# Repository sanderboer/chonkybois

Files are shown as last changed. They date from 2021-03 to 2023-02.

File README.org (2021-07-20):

* Lil Chonky Bois.

MX hotswap, wireless version.
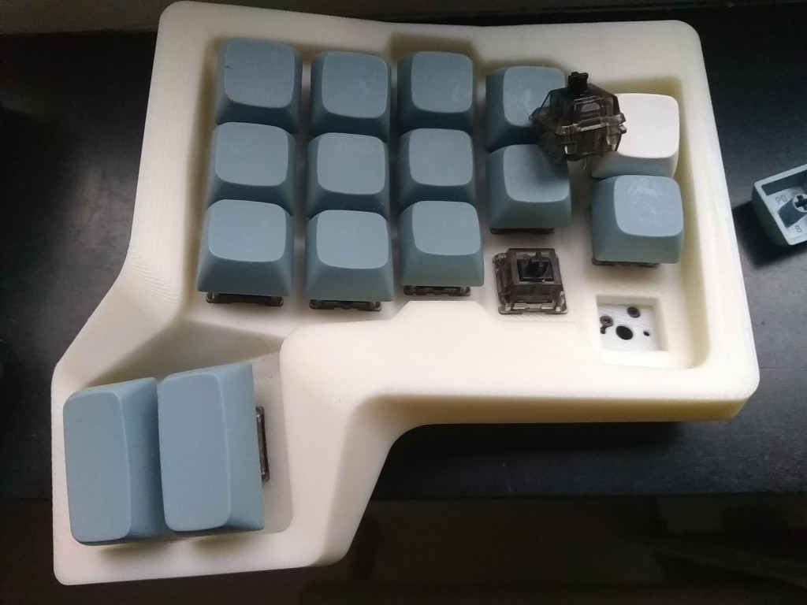
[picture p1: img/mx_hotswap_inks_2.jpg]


This is the case design for the Lil Chonky Bois, the successor of the original Chonky Boi, which has been moved to the archive.
The Chonky Bois come in different flavors, i.e. wired and wireless. The wireless version accomodates the [[https://store.jpconstantineau.com/#/group/bluemicro][bluemicro840 v1.x]] and the [[https://store.jpconstantineau.com/#/group/bluemicro][bluemacro840 v1.x]]. Rumor has it that the Nice!Nanos are going to be in stock again in the nearnear future, when I can get a hold of a couple, I will update this repo with a holder for it, providing the original promicro holder will not suffice.
Furthermore, MX hotswap and ALPS mountplate versions are provided.

* Hot Swap
Having started with handwired alps keyboards, repurposing AEKII switches, I turned my nose up to hotswappable keyboards. This was wrong, like very wrong. What I did not know at the time was how rich and diverse the MX switch landscape had become. At the time I only had silent white alps and if I looked far and wide on the internet, maybe, just maybe I could find a batch of affordable blue or orange alps. Three types of switches was managable.

When I made an MX version I quickly fell into a rabbit hole of blues (yuck), browns (oof), yellows (hello), glorious pandas (wat) and black inks (fuyooo) and I have barely scratched the surface. No, like lubing and filming your switches, I now consider hotswap to be *mandatory* for any keyboard enthousiast. I manage to solder a set in roughly two hours and my back hates it, if I see a nice switch set on ali (I see you tecsee purples) I do not want to think about breathing soldering fumes for another evening. No, I want to think about the taste of krytox 205g0 on my fingers instead ! /s

* Extras

** Wrist rests
For conveniece, several wrist rests are provided in a separate blend file, the gel version has also been exported as an stl. Please note that I am using some weird rubber feet I found in a craft store, sold by the pound and you will need to accomodate accordingly.

** Switch fit tester / Super Awesome Fidget Unit.
Essentially I lifted three homerow keys out of the right side and modeled it into a tester to test switch fit and to test the switch feel.
Put a lubed and unlubed switch in here and amaze your friends !
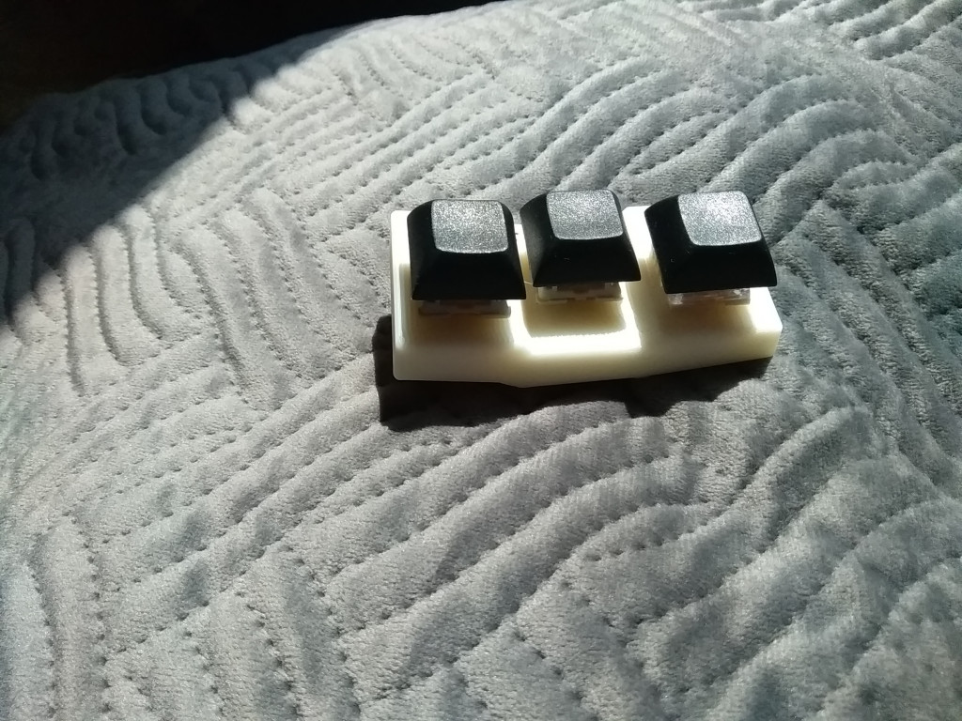
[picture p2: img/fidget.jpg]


* BOM

** General
| type                                 | amount | remarks                                                                               | link      |
|                                      |        |                                                                                       |           |
|--------------------------------------+--------+---------------------------------------------------------------------------------------+-----------|
| knurled inserts                      |     12 | M3 x D5 x  L4.0                                                                       | [[https://nl.aliexpress.com/item/4000232858343.html][ali]]       |
| m3 screws                            | 6 or 8 | flathead or roundhead                                                                 | [[https://nl.aliexpress.com/item/4000742472778.html?spm=a2g0o.store_pc_groupList.8148356.1.4b54694dlYVj6k][ali]]       |
| Kailh hotswap sockets                |     34 |                                                                                       | [[https://nl.aliexpress.com/item/4001051840976.html?spm=a2g0s.9042311.0.0.27424c4duT8R5v][ali]] [[https://ymdk.nl.aliexpress.com/store/429151][ymdk]]  |
| switches                             |     34 | glorious pandas (tactile), gateron inks (linear) or kailh box blues (clicky) or...    | [[https://nl.aliexpress.com/item/1005001678253507.html?spm=a2g0s.9042311.0.0.27424c4dcuYsDy][ali]] [[https://ymdk.nl.aliexpress.com/store/429151][ymdk]]  |
| switch lube and station              |    n/a | Optional, but if you are not lubing your switches, why are you here ?                 | [[https://nl.aliexpress.com/item/4001287632004.html?spm=a2g0s.9042311.0.0.27424c4dP1bmnZ][ali]] [[https://ymdk.nl.aliexpress.com/store/429151][ymdk]]  |
| 1n4148 diodes                        |     34 |                                                                                       | [[https://nl.aliexpress.com/item/1934432186.html?spm=a2g0s.9042311.0.0.27424c4dCcuaFD][ali]]       |
| grippy rubber                        |    n/a | To keep the kb from sliding, harder to find than I'd like to admit                    | [[https://nl.aliexpress.com/item/4000013831045.html?spm=a2g0s.9042311.0.0.27424c4d6xGt3Y][ali]]       |
| color coated copper wire             |        | Optional, but the color coding and the thin wires really suit this project            | [[https://www.aliexpress.com/item/1005001321847977.html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,searchweb201602_,searchweb201603_][ali]]       |
| keycaps dsa/xda                      |     34 | 30x1u and 4x1.5u                                                                      | [[https://nl.aliexpress.com/item/1005001376888502.html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,scm-url:1007.30114.213637.0,pvid:67330b30-a52a-417b-af98-0368b264de63,tpp_buckets:668%230%23131923%2375_668%23888%233325%2311_20114%230%23213637%235_20114%233258%2310449%2333_668%232846%238114%231999_668%235811%2327185%2368_668%236421%2330822%23182_668%232717%237567%23922__668%233374%2315176%23590_19670%230%23233084%230_19670%233636%2316450%23358_19670%234867%2324465%23166_19670%235271%2324224%23319_19670%233633%2316436%23436_19670%232760%237734%23528_19670%233043%239190%239_19670%235119%2323475%23944&&pdp_ext_f=%257B%2522scene%2522%253A%252220114%2522%257D][ali]]  [[https://ymdk.nl.aliexpress.com/store/429151][ymdk]] |
| gel superglue                        |      1 | The hotswap sockets are glued in place, gel is better with filling printed gaps      | [[https://www.bol.com/nl/nl/p/pattex-superglue-ultra-mini-gel-trio-3-tubes-1-g/9200000124384556/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][bol]]       |
|--------------------------------------+--------+---------------------------------------------------------------------------------------+-----------|
| WIRELESS                             |        |                                                                                       |           |
| bluemicro840 v1.x/bluemacro 840 v1.x |      2 | Do not mix micro and macro                                                           | [[https://store.jpconstantineau.com/#/group/bluemicro][store]]     |
| micro reset switch                   |      2 | Hardware reset switch; boards need double click to be put into dfu mode              | [[https://nl.aliexpress.com/item/32919212895.html?spm=a2g0s.9042311.0.0.27424c4dsfyf3P][ali]]       |
| jst connector                        |      1 | one 4-pin male and female;disconnecting the botplate is a quality of life option.    | [[https://nl.aliexpress.com/item/32963843207.html?spm=a2g0s.9042311.0.0.27424c4dZ8ET6k][ali]]       |
| On/Off switch                        |      2 |                                                                                       | [[https://nl.aliexpress.com/item/32952489874.html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][ali]]       |
| LiPo battery                         |      2 | Shipping to your country could be an issue, check local drone tech suppliers.         | [[https://nl.aliexpress.com/item/32977525312.html?spm=a2g0s.9042311.0.0.27424c4dynClON][ali]]       |
|--------------------------------------+--------+---------------------------------------------------------------------------------------+-----------|
| WIRED                                |        |                                                                                       |           |
| Pro Micro MCU                        |      2 | Elite-C (usb-c) or teensy 2.0 (usb-mini) are viable alternatives                      | [[https://nl.aliexpress.com/item/32768308647.html?spm=a2g0s.9042311.0.0.27424c4dS8z6Py][ali]]       |
| TRSS connector                       |      2 | Needs to be stereo                                                                   | [[https://nl.aliexpress.com/item/4000640677390.html?spm=a2g0s.9042311.0.0.27424c4dX6v9oC][ali]]       |
| TRSS cable                           |      1 | Or any old male-male stereo 2.5 mm jack audio aux cable.                              | [[https://nl.aliexpress.com/item/32459681560.html?spm=a2g0s.9042311.0.0.27424c4dynClON][ali]]       |
|--------------------------------------+--------+---------------------------------------------------------------------------------------+-----------|
| ALPS                                 |        |                                                                                       |           |
| Alps no name clone                   |        | Still waiting on delivery,so untested as yet. Get an old apple AEKII on ebay instead. | [[https://nl.aliexpress.com/item/32654107324.html?spm=a2g0s.9042311.0.0.2b254c4drfqukj][ali]]       |
|--------------------------------------+--------+---------------------------------------------------------------------------------------+-----------|
| MISC / Quality of life               |        |                                                                                       |           |
| Gel wrist rest                       |      2 |                                                                                       | [[https://nl.aliexpress.com/item/32894937019.html?spm=a2g0s.9042311.0.0.27424c4d6VJaFU][ali]]       |
| Crimp tool                           |      1 | For your jst connectors, and the molex connectors in your maker future.              | [[https://nl.aliexpress.com/item/32910569929.html?spm=a2g0s.9042311.0.0.27424c4dZ8ET6k][ali]]       |
| Superglue accelerator / activator    |        | Check your local hardware store.                                                      |           |

* Firmware

** Wired
For the wired version, QMK is the way to go, I maintain a form of qmk with a keymap for the Lil Chonky Bois:

https://github.com/sanderboer/qmk_firmware

** Wireless

*** BluemicroBLE
Similarly I maintain my keymap for the wireless build in my own fork of BlueMicroBLE (lil_chonky_kb branch):

https://github.com/sanderboer/BlueMicro_BLE/tree/lil_chonky_kb

Please refer to the BlueMicroBLE docs for installing the build env, additional setup and build script for linux is in the root of my for of the repo.
Please let me express my extreme gratitude to [[https://github.com/jpconstantineau/][Pierre Constantineau]], the creator of the bluemicro840, for his extremely patient and helpful guidance on discord in setting up the boards and showing me just how deep the rabbit hole of bluetooth voodoo goes. 

*** ZMK
And as an alternative I also have my keymap implemented in my ZMK fork (lil_chonky  branch):

https://github.com/sanderboer/zmk/tree/lil_chonky

Please refer to the ZMK docs for setup the build env, build script for linux is in the app/boards/shields/lil_conky_bois/ dir
* Images

Bluemacro840 under construction
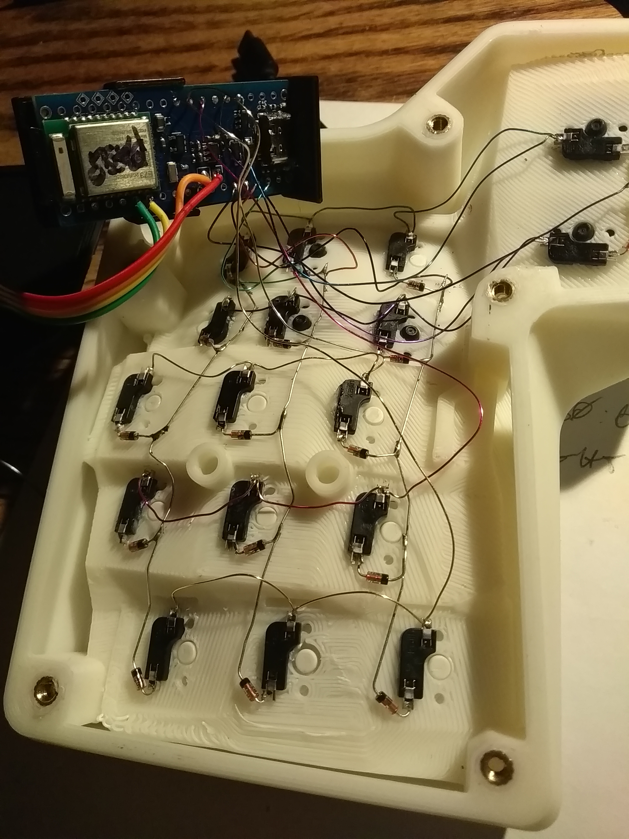
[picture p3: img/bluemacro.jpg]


Wired version in the background with wrist rests, wired version showing its guts. Note the removable botplate thanks to the jst connectors.
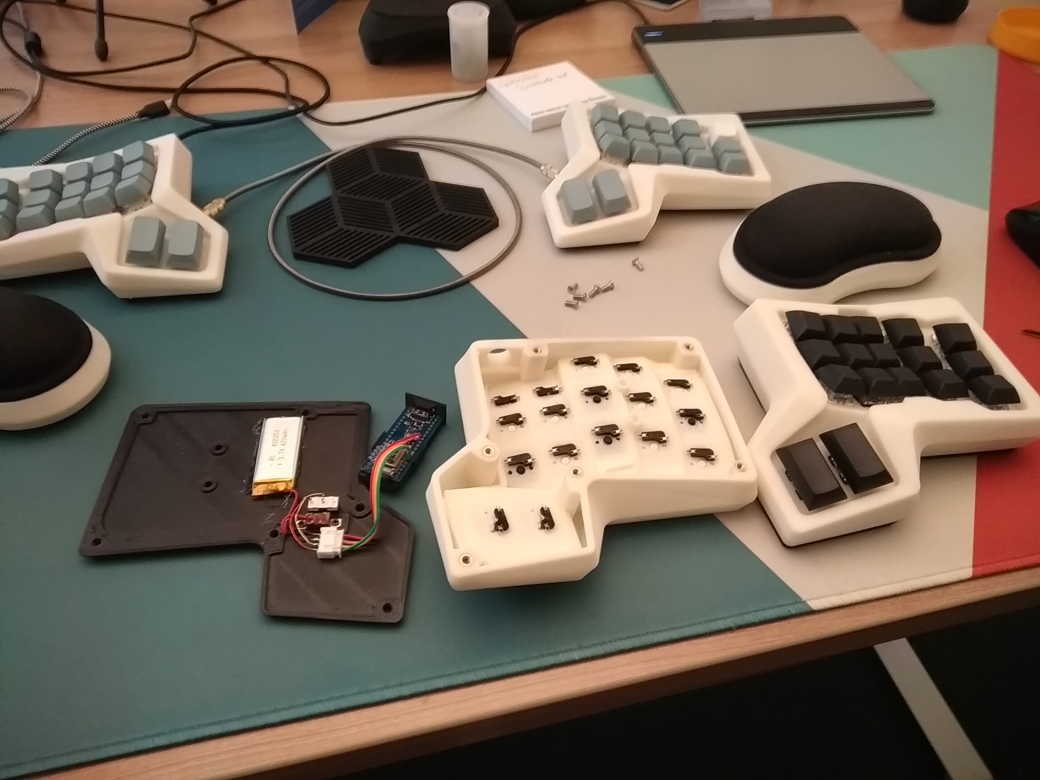
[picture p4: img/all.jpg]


The original Big Chonky Bois and Lil CHonky Bois that started it all.
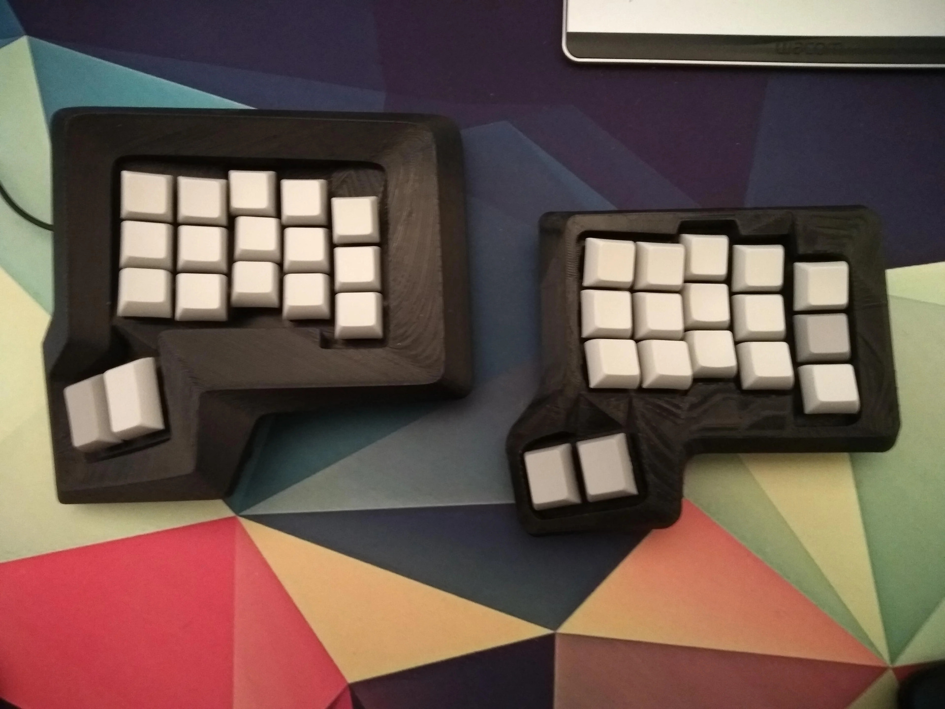
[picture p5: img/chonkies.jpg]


Lil Chonky in ALps and MX version. 


Wired version, XDA keycaps.





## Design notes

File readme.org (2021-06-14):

* Lil Chonky v 1.1

#+CAPTION: Lil Chonky in ALps and MX version. 


This is the next iteration of the original lil Chonkster, after using the previous incarnation for a couple of months I decided to ease the tenting and I found I needed a little less curvature of the keywell. After some testing I also adapted the thumbcluster a little. Pictured are the Alps and the MX version, the thumbcluster is designed for 1.75u keycaps and for MX keys these are harder to come by than imagined. In the BOM is a link to an ALI store that allows you to order any format, but 1.75u is calculated as having the price of 4x 1u.

* Punk Rock Hot Swap
Strictly speaking this is not part of the design, but it is part of my build. During the design iterations I changed cases a number of times and I got real sick of the resoldering. Not so much the work itself, but I felt there was a real degradation happening with each resolder.
I found an example of somebody using small rivets in stead of the mill-max connectors. The plan is to put a small rivet over one of the legs of a switch, use pliers to squash the rivet on the leg. Then comes the intersting bit, this squashed rivet will too easily come off, now you must remove the rivet from the leg and give it an extra squeeze. Too hard and it will not go over the leg again, too little, it will come loose too easily, repeat until a healthy friction fit is achieved.




* BOM



- 12 x knurled inserts M3 x D5 x  L4.0
https://nl.aliexpress.com/item/4000232858343.html
- rivets for punk rock hotswap
https://nl.aliexpress.com/item/32955662951.html
- 12 m3 x 6(or 8) screws. I had round head laying around, but flat heads are more practical: https://nl.aliexpress.com/item/4000742472778.html?spm=a2g0o.store_pc_groupList.8148356.1.4b54694dlYVj6k

- 34 switches.These Holy Pandas are amaze and kinda awesome: https://nl.aliexpress.com/item/1005001678253507.html?spm=a2g0s.9042311.0.0.27424c4dcuYsDy

- (optional) switch lube, station and opener https://nl.aliexpress.com/item/4001287632004.html?spm=a2g0s.9042311.0.0.27424c4dP1bmnZ

- 2 x TRSS connectors

- 34 x 1n4148 diodes. https://nl.aliexpress.com/item/1934432186.html?spm=a2g0s.9042311.0.0.27424c4dCcuaFD

- 30x dsa 1u keycaps, 4x  dsa 1.75u keycaps https://nl.aliexpress.com/item/32850729893.html

- 2x pro micro https://nl.aliexpress.com/item/32768308647.html?spm=a2g0s.9042311.0.0.27424c4dS8z6Py

- 1x sticky grippy rubber mat. https://nl.aliexpress.com/item/4000013831045.html?spm=a2g0s.9042311.0.0.27424c4d6xGt3Y

- (optional) color coated copper wire.
  untested link of a product that looks like the one I am using: https://www.aliexpress.com/item/1005001321847977.html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,searchweb201602_,searchweb201603_
  
* Images









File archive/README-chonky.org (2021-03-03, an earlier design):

* Chonky Bois

#+CAPTION: Big Chonky and the first lil Chonky.


 This is the home of the Chonky Bois ergo split keyboard models.
 Here you can find 3d models that once printed, fit alps or mx switches, a trss connector and a pro-micro and after some handwiring magic you can head over to my qmk fork for an example of a keymap/ 

** Lil Chonky
What started with the Big Chonky evolved into a more petite size.

#+CAPTION: Lil Chonky with the pinky rotation.


For this one I wrote a quick port of Matt Adereth's dactyl code to generate the shape of the keywells and the shape of the cavities for the switches. The intention is that one can model a basic shape around the generated keywell shapes.
I added a pinky rotation option as I found it to be very comfortable on the Absolem keyboard.

Generated model:


Finale model example:
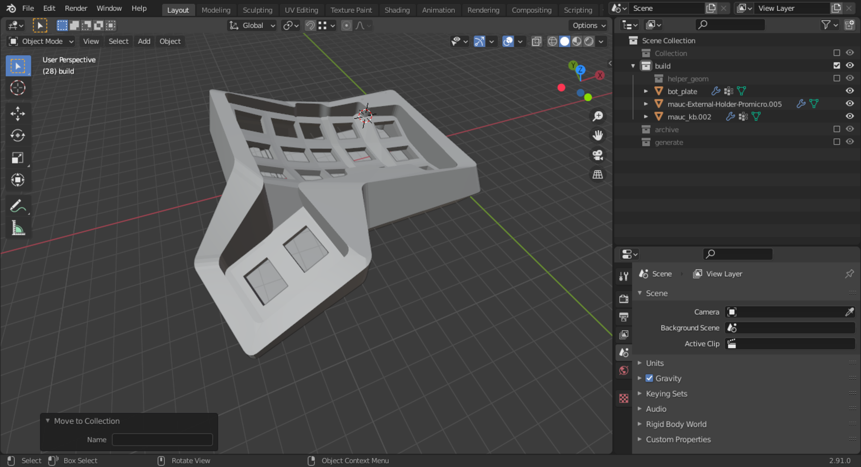
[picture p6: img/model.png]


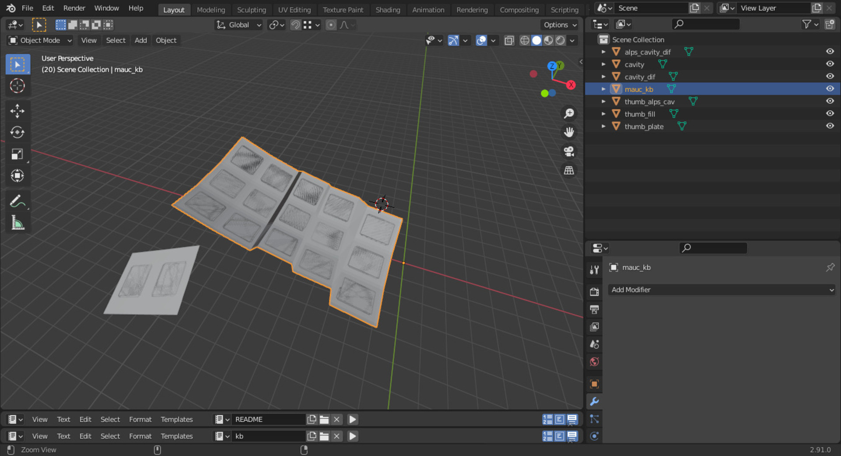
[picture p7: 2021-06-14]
img/generate.jpg

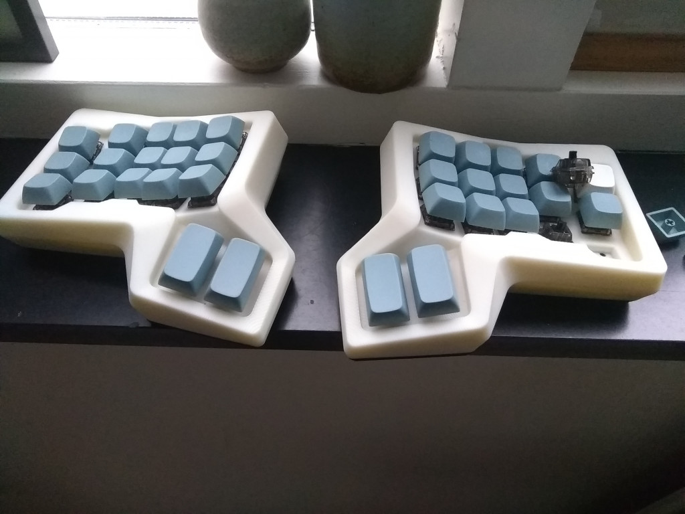
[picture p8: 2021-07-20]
img/bt.jpg

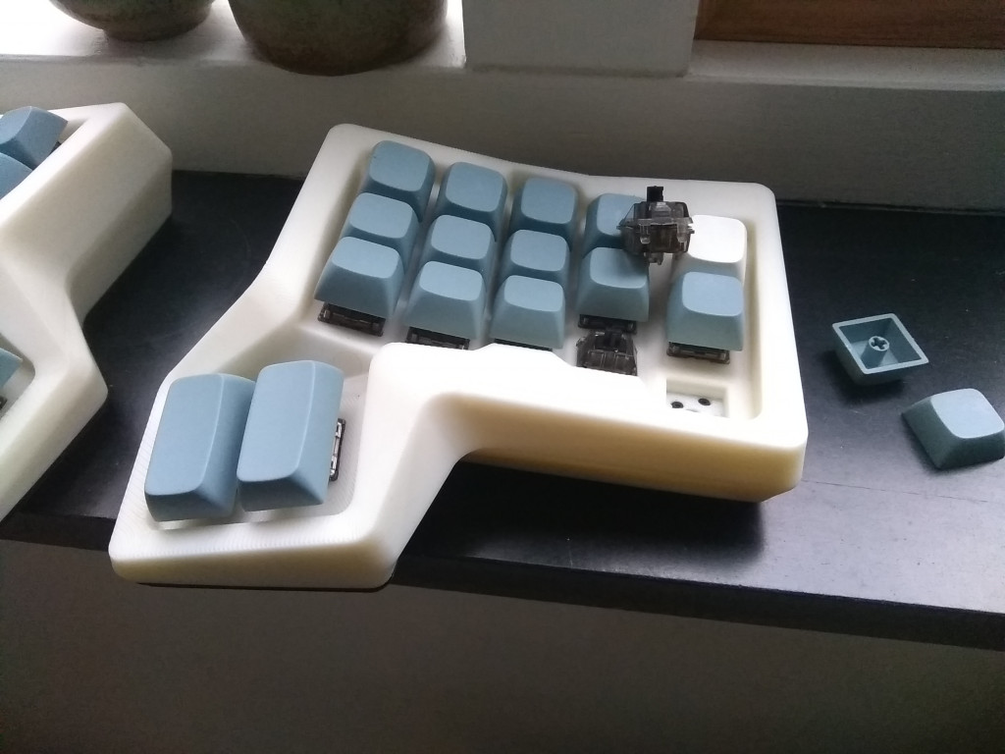
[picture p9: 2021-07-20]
img/mx-hotswap-inks.jpg

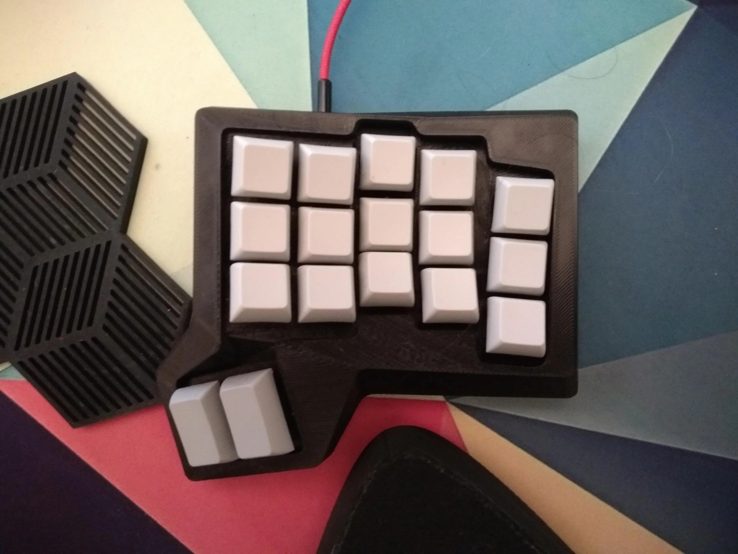
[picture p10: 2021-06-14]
img/lil_top.jpg

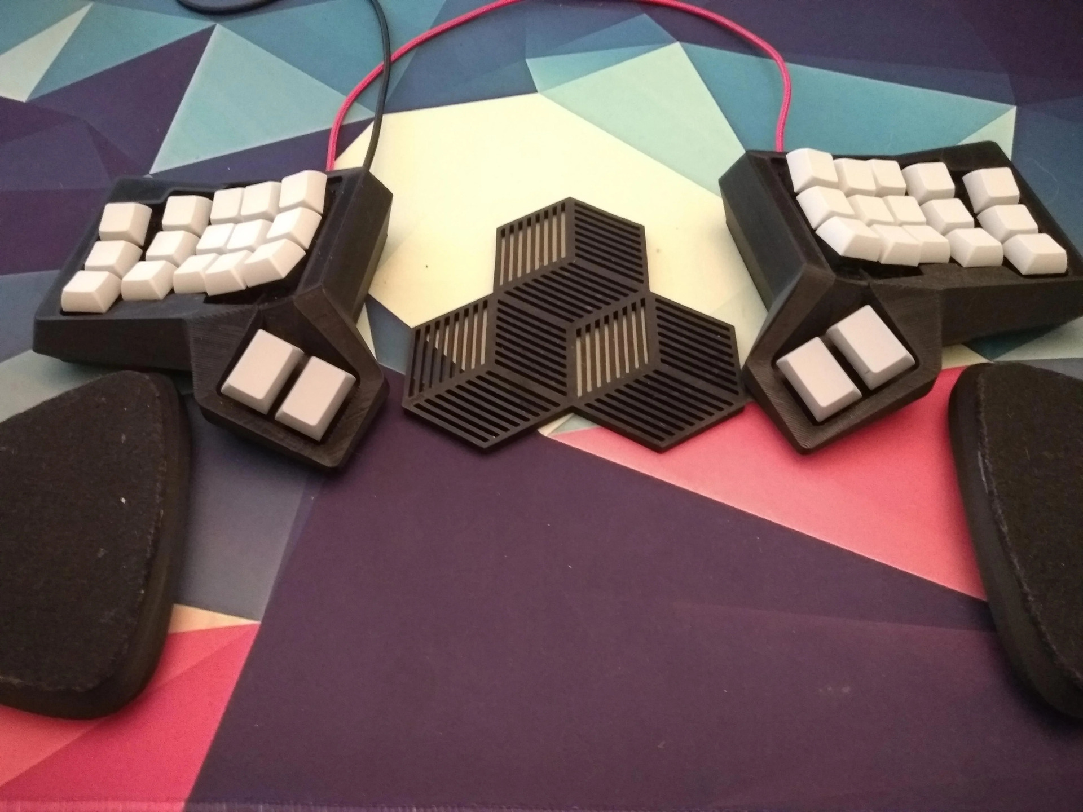
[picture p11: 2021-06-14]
img/lil.jpg

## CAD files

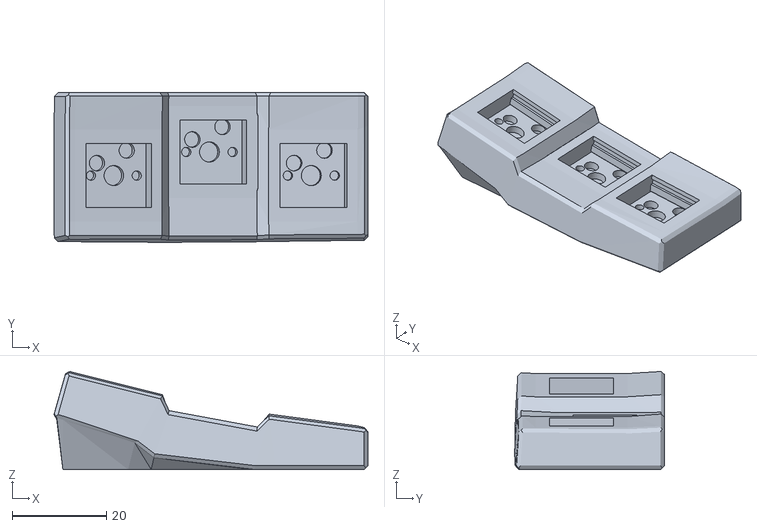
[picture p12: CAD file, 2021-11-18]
fidget_tester.stl
66.5 x 31.7 x 20.8

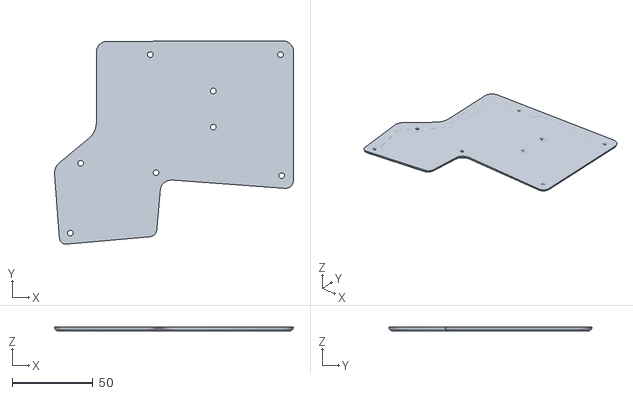
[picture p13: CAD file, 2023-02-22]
stl_wired/case_bot_right_wired_solid.stl
147.6 x 125.5 x 2.18

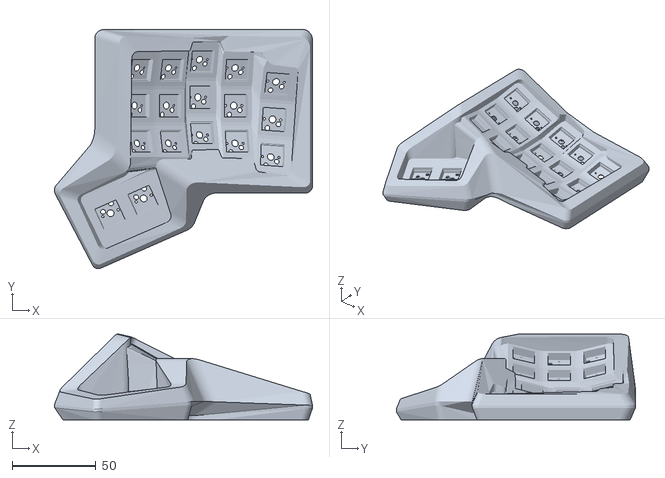
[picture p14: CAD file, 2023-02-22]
stl_wireless/generator_3x5-curvycase-right.stl
154.2 x 143.1 x 51.3

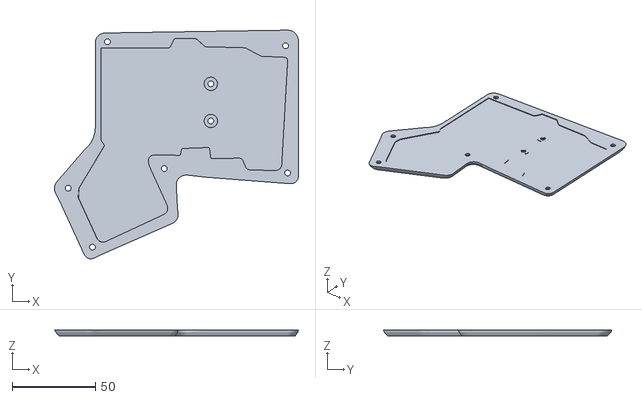
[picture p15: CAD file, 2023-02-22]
stl_wired/curvy-3x5-case-right-bot.stl
146.3 x 137.2 x 3.68

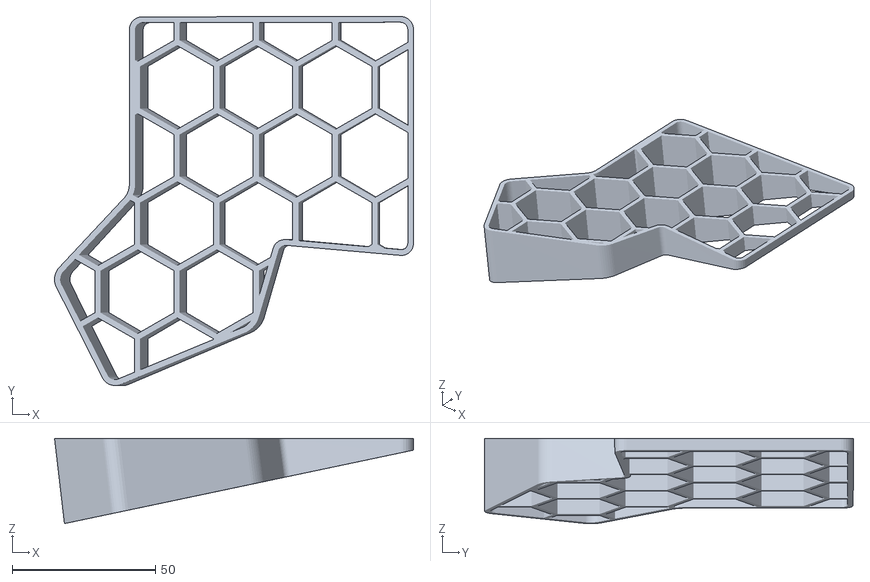
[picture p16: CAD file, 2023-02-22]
stl_wireless/generator_3x5-curvycase_009.stl
125.4 x 128.9 x 29.8

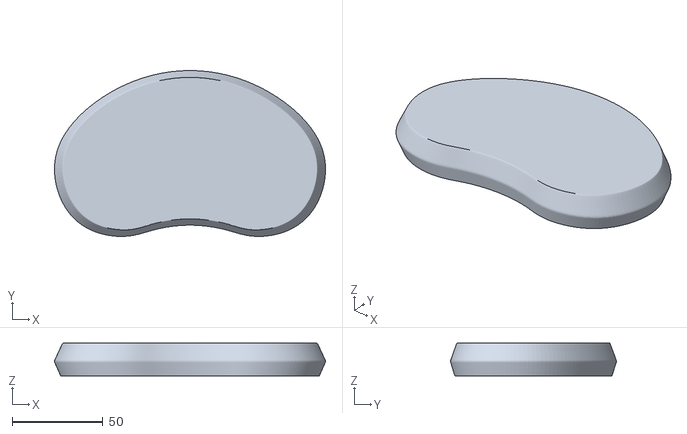
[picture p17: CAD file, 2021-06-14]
wrist-rest-gel_x2.stl
149.2 x 91.3 x 18.1

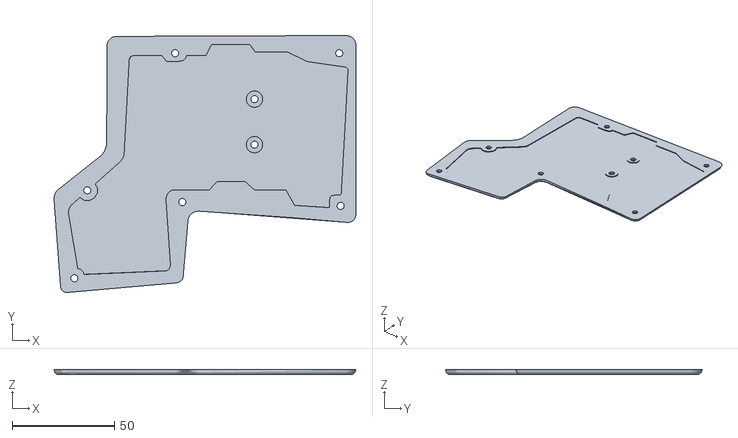
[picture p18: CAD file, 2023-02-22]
stl_wired/case_bot_right_wired_micro_solid.stl
147.9 x 125.9 x 2.43

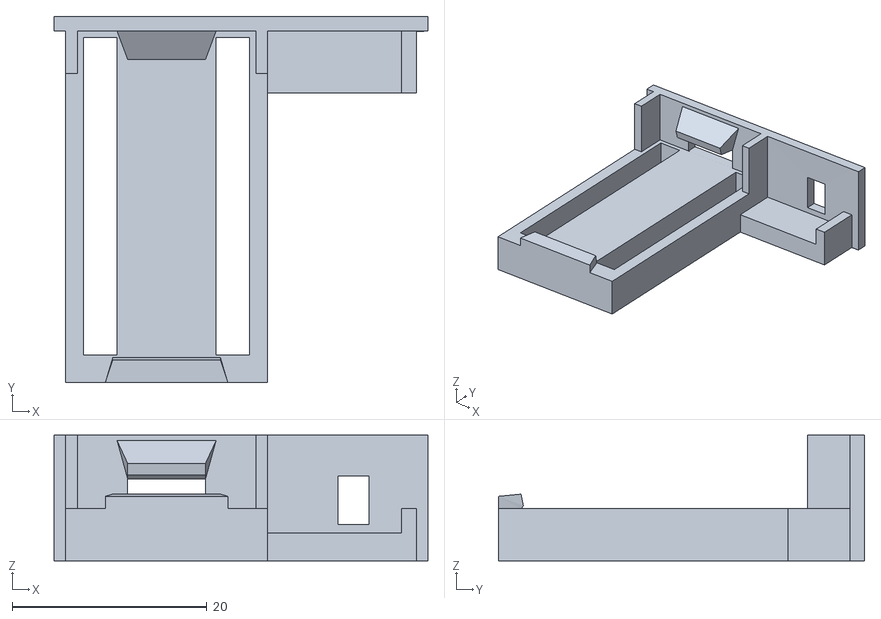
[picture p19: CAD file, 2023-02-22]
stl_wireless/generator_3x5-curvymauc-External-Holder-nicenano_x2.stl
38.4 x 37.7 x 12.9

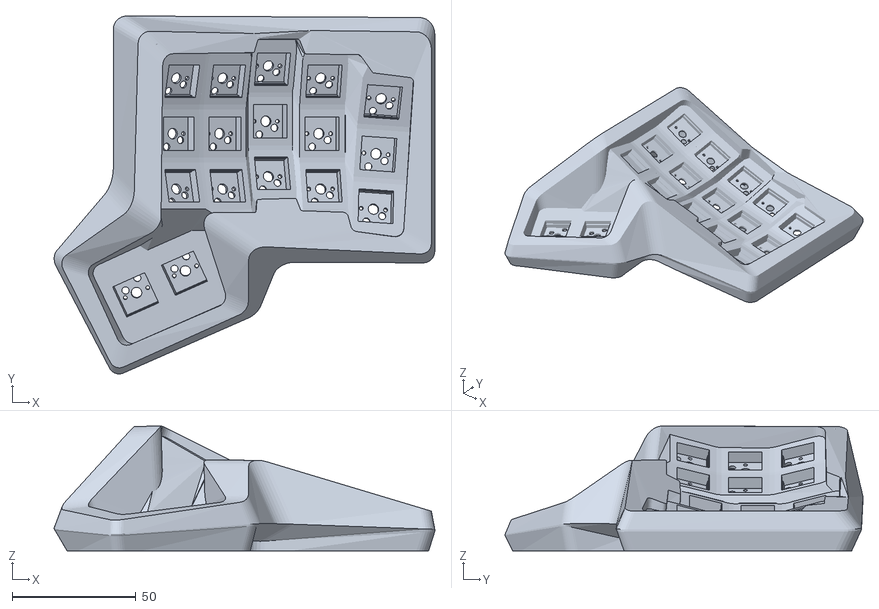
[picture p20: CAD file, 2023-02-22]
stl_wired/curvy-3x5-case-right.stl
154.1 x 144.9 x 50.5

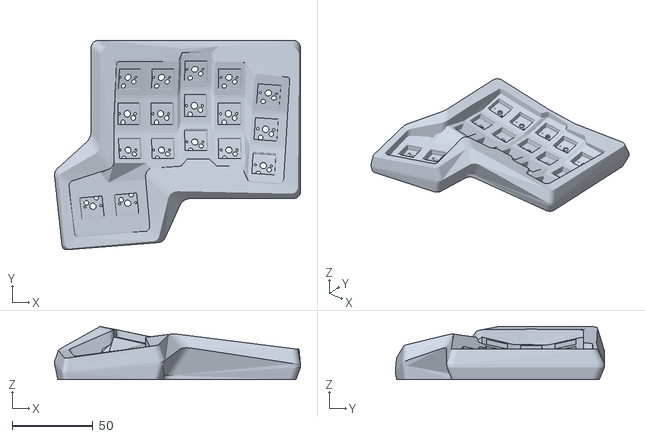
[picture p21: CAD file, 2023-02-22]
stl_wired/case_top_right_wired_micro_solid.stl
152.8 x 130.1 x 32.9

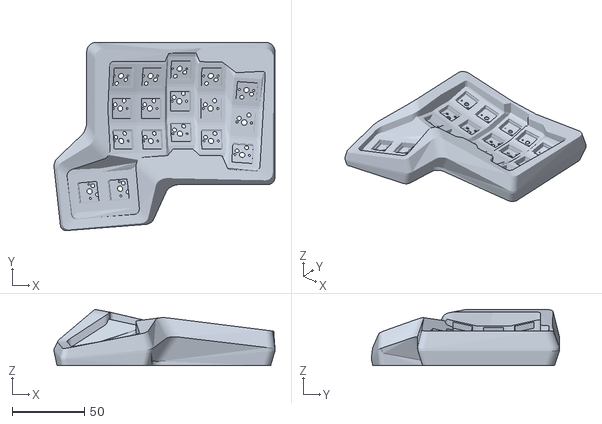
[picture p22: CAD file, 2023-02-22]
stl_wired/case_top_right_wired_solid.stl
152.6 x 130.0 x 38.9

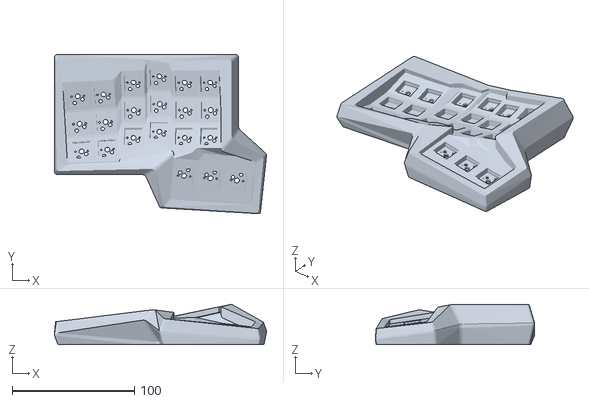
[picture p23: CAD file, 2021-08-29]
stl_wireless/case_top_left_wireless_kurtis.stl
173.1 x 130.2 x 32.9

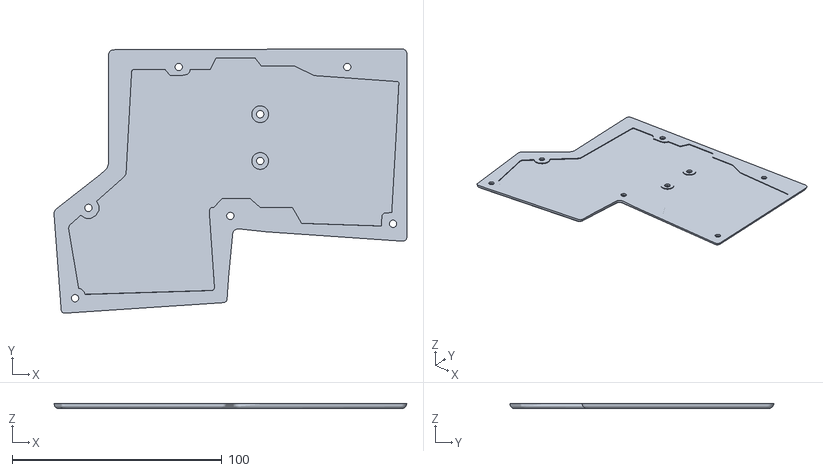
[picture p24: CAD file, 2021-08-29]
stl_wireless/case_bot_right_wireless_kurtis.stl
168.3 x 126.0 x 2.43

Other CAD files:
stl_wireless/generator_3x5-curvycase-left.stl
stl_wireless/generator_3x5-curvycase-right-bot.stl
stl_wired/curvy-3x5-case-left.stl
stl_wireless/case_top_right_wireless_kurtis.stl
stl_wired/case_top_left_wired_solid.stl
archive/absolem.blend
archive/bois-pcb-layout.3dm
archive/bois-pcb-layout.dxf
archive/chonky/chonkyBois.blend
archive/chonky/stl/chonkyBois_botplate_left.stl
archive/chonky/stl/chonkyBois_botplate_right.stl
archive/chonky/stl/chonkyBois_mcu_holder.stl
archive/hotswap stl files/choc keycap.stl
archive/hotswap stl files/hotswap MX base.stl
archive/hotswap stl files/hotswap MX clip left.stl
archive/hotswap stl files/hotswap MX clip right.stl
archive/hotswap stl files/hotswap choc base.stl
archive/hotswap stl files/hotswap choc clip left.stl
archive/hotswap stl files/hotswap choc clip right.stl
archive/kaihl_hotswap.blend
archive/kailh-hotswp-low-profile.blend
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

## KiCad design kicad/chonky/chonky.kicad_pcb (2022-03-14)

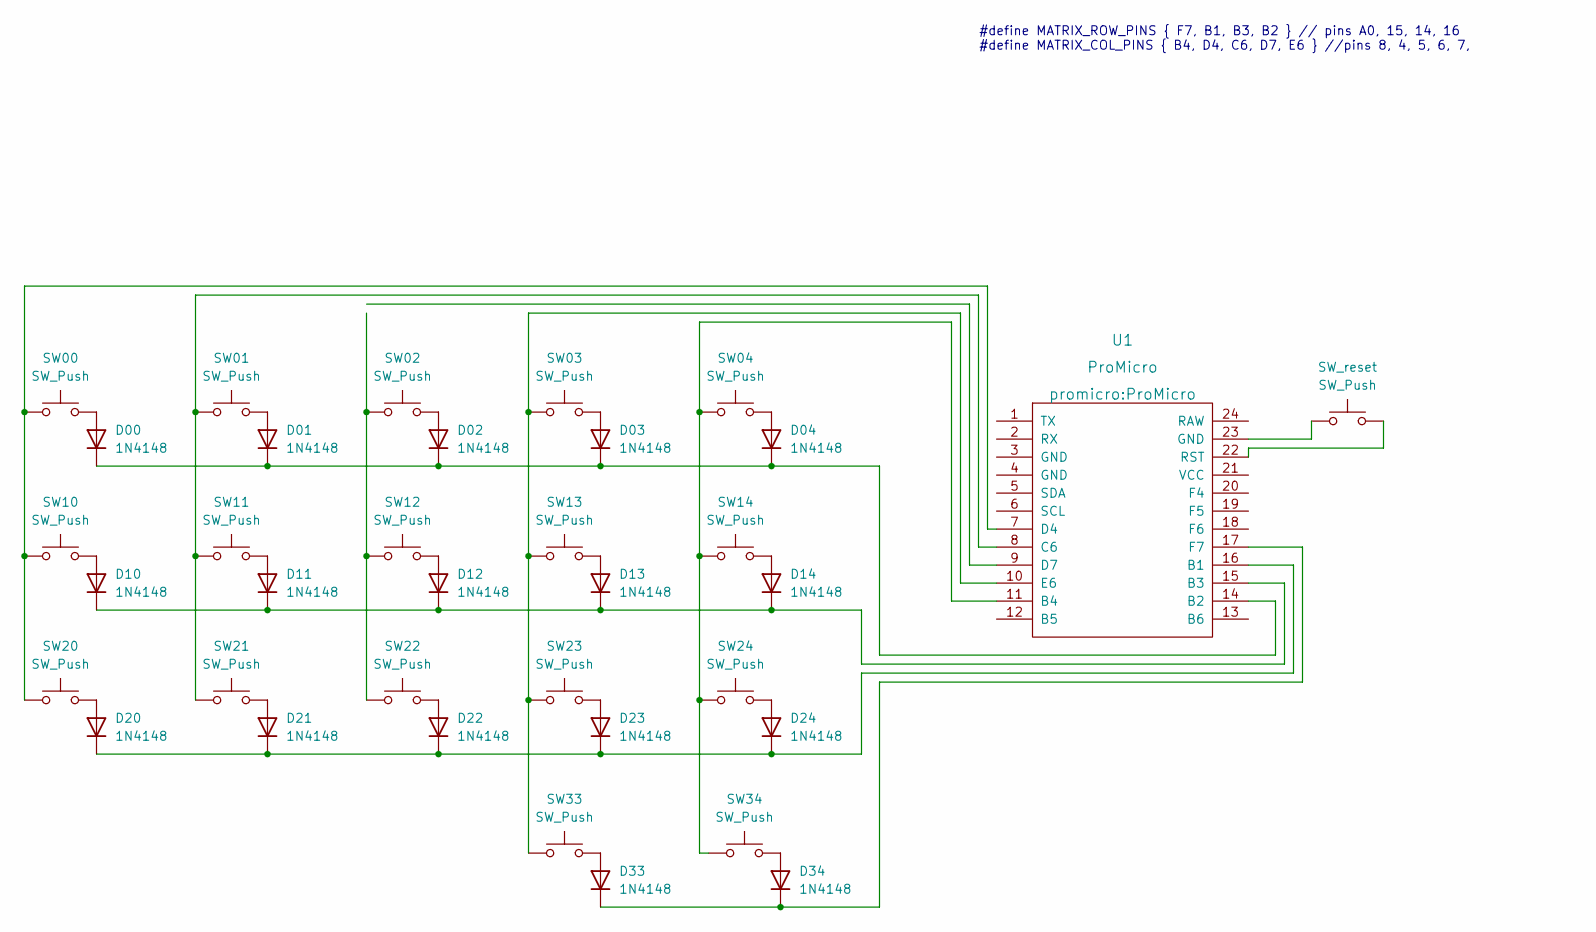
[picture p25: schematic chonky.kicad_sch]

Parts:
D00, D01, D02, D03, D04, D10, D11, D12, D13, D14, D20, D21, D22, D23, D24, D33, D34: 1N4148; D_DO-35_SOD27_P7.62mm_Horizontal
SW00, SW01, SW02, SW03, SW04, SW10, SW11, SW12, SW13, SW14, SW20, SW21, SW22, SW23, SW24, SW33, SW34: SW_Push; Kailh_socket_MX
SW_reset: SW_Push; Kailh_socket_MX
U1: ProMicro

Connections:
unnamed: D00.1 (K), D01.1 (K), D02.1 (K), D03.1 (K), D04.1 (K), U1.14 (B2)
unnamed: D00.2 (A), SW00.2
unnamed: D01.2 (A), SW01.2
unnamed: D02.2 (A), SW02.2
unnamed: D03.2 (A), SW03.2
unnamed: D04.2 (A), SW04.2
unnamed: D10.2 (A), SW10.2
unnamed: D11.2 (A), SW11.2
unnamed: D12.2 (A), SW12.2
unnamed: D10.1 (K), D11.1 (K), D12.1 (K), D13.1 (K), D14.1 (K), U1.15 (B3)
unnamed: D13.2 (A), SW13.2
unnamed: D14.2 (A), SW14.2
unnamed: D20.2 (A), SW20.2
unnamed: D21.2 (A), SW21.2
unnamed: D22.2 (A), SW22.2
unnamed: D20.1 (K), D21.1 (K), D22.1 (K), D23.1 (K), D24.1 (K), U1.16 (B1)
unnamed: D23.2 (A), SW23.2
unnamed: D24.2 (A), SW24.2
unnamed: D33.1 (K), D34.1 (K), U1.17 (F7)
unnamed: D33.2 (A), SW33.2
unnamed: D34.2 (A), SW34.2
unnamed: SW00.1, SW10.1, SW20.1, U1.7 (D4)
unnamed: SW01.1, SW11.1, SW21.1, U1.8 (C6)
unnamed: SW02.1, SW12.1, SW22.1
unnamed: SW03.1, SW13.1, SW23.1, SW33.1, U1.10 (E6)
unnamed: SW04.1, SW14.1, SW24.1, SW34.1, U1.11 (B4)
unnamed: SW_reset.1, U1.23 (GND)
unnamed: SW_reset.2, U1.22 (RST)

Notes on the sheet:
#define MATRIX_ROW_PINS { F7, B1, B3, B2 } // pins A0, 15, 14, 16 #define MATRIX_COL_PINS { B4, D4, C6, D7, E6 } //pins 8, 4, 5, 6, 7,

Board: 2 copper layers, 35 parts (0 on the bottom side), 26 nets, no tracks yet.

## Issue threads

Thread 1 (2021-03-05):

Adding a key to the thumb cluster

fi0, 2021-03-05:
Thank you for sharing the model!
Is the generator script available? I'm trying to add a key to the thumb cluster and would love some tips :)

sanderboer, 2021-03-05:
The script is embedded in the generator.blend file.
Change the script at line 250 to:

thumb_grid = grid(rows=3, cols=1, edge_align=False, gutter=2, grid_width=28.75, alpha=1, beta=1)

press the play button in the title bar of the script editor,
Now start futzing around line 274 to place and orient the thumbcluster
`for o in ['thumb_fill', 'thumb_plate','thumb_alps_cav']:
    mesh_trans(bpy.data.objects[o], ry=10)
    mesh_trans(bpy.data.objects[o], rx=20)
    mesh_trans(bpy.data.objects[o], rz=-77)

    mesh_trans(bpy.data.objects[o], dx=-105)
    mesh_trans(bpy.data.objects[o], dy=-61)
    mesh_trans(bpy.data.objects[o], dz=0)
`
dx moves it left, dz moves it up/down in mm.

fi0, 2021-03-05:
Thank you very much! I'll try.

fi0, 2021-03-19:
How do I generate the case after modifying generator.blend?
Or, how do I link up the lil_chonky_bois.blend with generator.blend?

sanderboer, 2021-03-19:
I'm afraid you have to model it yourself.
What I would do is this:
- save the generator model with the new base meshes as a new file
- join the base thumbplate and the base mountplate into a single mesh (ctrl-j with both meshes selected)
- add a solidify modifier to this mesh, set thickness to 4-ish
- join the thumb and base cavity meshes similarly, make sure you combine the right cavity meshes (alps vs cherry, cherry is square, alps are oblong)
- add a solidify modifier to the cavity mesh also, but set thickness to 20-ish,
- add a boolean modifier to the base mount plate mesh from earlier and select the cavity mesh as the mesh to cut with, (this is why I call it a cavity mesh). Result should be a mountplate with holes for switches.
- select the base mesh, go into edit mode (press tab to toggle object and edit mode) and add faces between thumb and base.
- rename the base mesh to something sensible

Now save this file and open another blender instance, load the lilchonky model.
When you inspect my keyboard model (mauc_kb.002 if I recall correctly) you see that this model has a huge modifier stack.
The second modifier from the top is a boolean Add modifier.
Now file->append and select your file where you saved your sensibly named mountplate, -> Object -> your sensibly named object
Now you have your new sensibly named mountplate (and the mesh used in the cavity boolean) in this file.

Select the mauc_kb.002 model and go into the modifier stack, find the add boolean where my mount_plate_alps_edit is added to the kb and swap it for your mountplate model.
You should now have a model of a keyboard with your mountplate and it will probably not fit, now it is time to adjust the mesh of the model by hand to make all fit.

fi0, 2021-03-24:
Thank you for the writeup! I'll learn more about blender first :p

Closed 2021-03-05.

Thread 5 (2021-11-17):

fidget_tester.stl is blank

clverkuilen, 2021-11-17:
When opening the fidget_tester.stl file, Cura says it's either corrupt, inaccessible, or it did not contain any models. The stl preview in Github doesn't show any model either.

sanderboer, 2021-11-18:
oopsiedoodle; fixed

Closed 2021-11-18.

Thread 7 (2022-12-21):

Requesting 3x6 Kurtis stls

sagepeppermint, 2022-12-21:
Hi, struggling figuring out how to generate the STLs from blender,
want them produced for the generator_3x6_kurtis-flat file so i can print it out.
Thanks

sagepeppermint, 2022-12-21:
nevermind found it in the wireless STL folder

Closed 2022-12-21.

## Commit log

2021-03-03 the bois are here
    [chonkyBois.blend, chonkyBois_botplate_left.stl, chonkyBois_botplate_right.stl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]
2021-03-12 added more botplate holes for 2.5 mm threaded inserts
2021-03-13 fattened mountplate to 4 mm, more even with ring/pinky rows to help w printing. Mid ring finger tended to jump off print bed bc of lacking adhesion with abs.
2021-03-16 Too lazy to comment
    [test.blend]
2021-08-28 working on a low-profile one without curvature
    [kailh-hotswp-low-profile.blend]
2021-08-28 Update generator_3x6_kurtis-flat.blend
    - Fixed bottom pinky screwhole placement
    - Fixed inheritance issues between "case.001", "case-left.001", "case-right.001", and "case-right-bot.001"
    - Fixed mountplate and thumbplate bridge
2021-08-29 Add corne-style STLs
    [case_bot_right_wireless_kurtis.stl, case_top_left_wireless_kurtis.stl, case_top_right_wireless_kurtis.stl]
2021-11-18 fidget tester stl repaired
    [fidget_tester.stl]
2022-06-13 Add lil chonky classic
    [External-Holder-Promicro.stl, alps_case_bot.stl, alps_case_top.stl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]
